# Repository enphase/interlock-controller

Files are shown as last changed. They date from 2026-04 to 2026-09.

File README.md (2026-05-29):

# interlock-controller

## ⚠️ DISCLAIMER ⚠️

This design is provided for reference and development purposes only.
It is not certified, not validated, and not intended for use as a safety‑critical control system without independent verification, validation, and certification by the user.
Enphase makes no representations regarding fitness for safety‑related use, including protection of persons, property, or equipment.

Any use of this design in systems that may cause harm, injury, or damage is solely at the user’s risk.
Users are responsible for compliance with applicable safety standards, regulations, and certifications.

## Introduction

This is a design for a controller box for an interlock system, including interface definitions, mechanical designs and wiring diagrams.
Broadly, it takes in inputs (like E-stops, magnetic sensors, and a start button) and provides outputs (closing an external dry contact loop) and a status light.
The design makes heavy use of 3d printing to be modular and allow iteration and design changes.

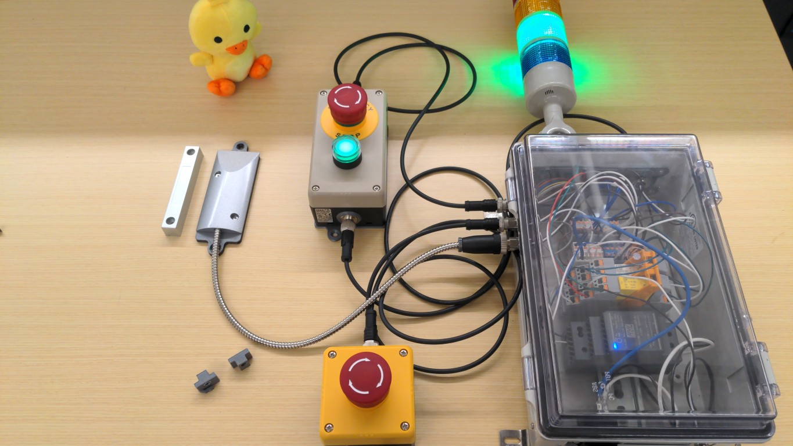
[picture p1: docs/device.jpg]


## General Design Rules

- Uses metric fasteners (M3 and M4 screws and nuts, both countersunk and pan head).
- 3d printed parts use friction-fit hex nuts.
- Uses 4-pin M12 connectors for sensors and outputs.
- Attaches to T-slot ("8020") framing, using M4 screws.

## Design Documents

[design.md](design.md) has detailed interface specifications.

## Mechanical Designs

Parts are designed in either Cadquery (a Python library for defining programmatic 3d designs) or FreeCAD.

Generated STLs are not committed to the repository, these can be generated by either running the CadQuery (`.py`) scripts or exporting from FreeCAD.
STLs MAY be included in the releases.

We have printed our parts on a Prusa XL using a high-flow 0.4mm nozzle and set for 0.2mm STRUCTURAL or 0.2mm BREAKAWAY INTERFACE, with PETG material (and PLA breakaway where needed).
These are expected to work on most FDM printers.
Unless otherwise noted, most parts can be printed in an orientation that does not require support. 

### T-slot Nuts

[tslot_nut.py](tslot_nut.py) generates a parametric T-slot nut with a hex nut pocket and spring arm to hold its position.
Print in PETG for flexibility of the spring arm.
You may need to tune parameters.

These are parameterized for 4545 metric T-slot framing.

### Controller Box and Connector Panels

The main controller box is a COTS box (NBB-10261) with machined cutouts (rounded rectangle + 4 M3 mounting holes) for 3d printed panels to fit connectors.
These can be purchased as a modified enclosure from Bud (with additional lead-time and $450 minimum order), through one of their distributors.
Alternatively, these can be machined (**not easily! needs special fixturing!**) on a manual mill and a 3/4" or 20mm end mill.

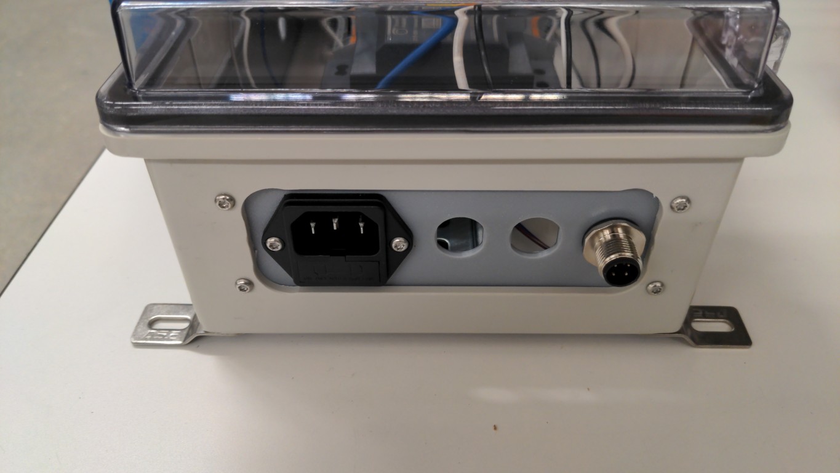
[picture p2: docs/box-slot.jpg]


Previously, this was two 116x40mm R10mm slots (top and bottom) and a 216x40mm R10mm slot (side), with M3 holes on a 124x32mm and 224x32mm pattern, respectively.
Newer version will have 116x40mm R10mm slots on three sides, with M3 holes on a 124x32mm pattern.

[connector_plate.py](connector_plate.py) generates the connector plates to fit into the cutouts.
These hold a M3 nut and have connector cutouts for eg, M12 connectors.

Electronics, like relays, are mounted to a DIN rail on the controller box.
The DIN rail is attached to factory-provided M4 threaded inserts / bosses in the box.
[din35_mount_stabilizer.py](din35_mount_stabilizer.py) generates a prismatic standoff that sits below the DIN rail to give it stability.
It can also be used to join two DIN rails back-to-back.
We use three of them: one next to each boss, and one to join two DIN rails; this seems to provide enough stability for DIN-mount spring-actuated terminal blocks.

If you are machining the box yourself, see [manufacturing-notes.md](manufacturing-notes.md).

See [design.md](design.md) for the electronics inside the box.

### Control Boxes

Human interface boxes (like for e-stop and pushbutton switches) use IDEC boxes like FB1W-111Y and FB2W-211Z, which are mounted to the T-slot framing using adapter plates.

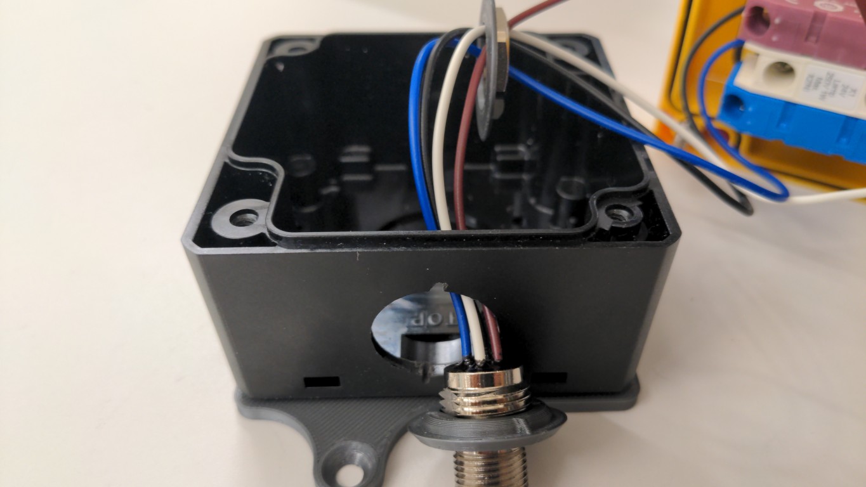
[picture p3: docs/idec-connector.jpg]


These have a 21.3mm punchout, which is too large for M12 connectors.
[idec_fb_m12_adapter.FCStd](idec_fb_m12_adapter.FCStd) and [idec_fb_m12_washer.FCStd](idec_fb_m12_washer.FCStd) "sandwich" the M12 connector to adapt it to the larger punchout.
idec_fb_m12_adapter.FCStd must be printed with supports, preferably two-material breakaway supports.
Because these add thickness, the O-ring on the M12 connectors must be removed.
Additionally, these have an anti-rotation feature, so a 1mm wide x 2mm long (radially outward) slot needs to be dremeled into the top of the punchout.
The anti-rotation feature is triangular, the slot does not have to be completely through.

[tslot_mounting_plate.py](tslot_mounting_plate.py) generates adapter plates that adapt the back of these boxes to attach to the T-slot framing.
These attach to the back of the IDEC box using M4 countersunk screws.
You will need to tap the factory holes on the box with a M4 tap.

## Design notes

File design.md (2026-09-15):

## External Connections

### Sensors

- 2x emergency stop switch w/ red light
  - This light indicates when the interlock is closed (output live)
- 1x magnetic door switch
- 1x start button w/ green light
  - This light indicates when the interlock is ready (output not live, but can be started by pushing this button)
  - Both e-stop lights AND start lights are on when the interlock is closed (output live).

### Output

- 1x dry contact output, connected to the test equipment interlock port
- 1x tower light
  - red = interlock closed (output live)
  - green = interlock open
  - no lights on or both lights on = invalid state
- Lights on e-stop and pushbuttons

## Interface definition

Inputs and outputs use M12 connectors, 4 or 5 pin versions, A-code.
For maximum compatibility, where not otherwise constrained, we use M12 4-position pins and M12 5-position sockets.

Outputs (eg, dry contact) are M12 sockets, while inputs (eg, sensors) are M12 pins.

The general pinning is, as consistent with IEC 60947‑5‑2:
- 1 (brown): +24v
- 3 (blue): 0v
- 2 (white): signal 1 (interlock loop source)
- 4 (black): signal 2 (interlock loop return)
- 5: disconnected where not used

Specific pinnings:
- For the e-stop: pin 1 (+24) is the interlock-closed +24v signal, which powers the e-stop light. 0v is always present.
- For the start button: pin 1 (+24) is the interlock-ready +24v signal, which powers the start button light. 0v is always present.
- For the tower light, if using M12 connectors: signal 1 is red, signal 2 is green (polarity dependent on the tower light configuration). 24v and 0v are always present.

Part selections:
- M12 5-position socket 0.2m pigtail: T4171310005-001
- M12 4-position pin 0.2m pigtail: T4171210004-001
- M12 5-position pin 0.2m pigtail (if needed): T4171210005-001
- Cables: M12A05ML-12AFL-Sx00x

## Electrical architecture

Internal wiring color conventions for terminal blocks and non-connector-pigtail wires ([source](https://industrialmonitordirect.com/blogs/knowledgebase/24v-dc-control-wiring-wire-color-codes-ul-en-standards)):
- Blue: +24v
- White: 0v
- Purple: interlock-ready +24v
- Orange: interlock-closed +24v
- Grey: general signal

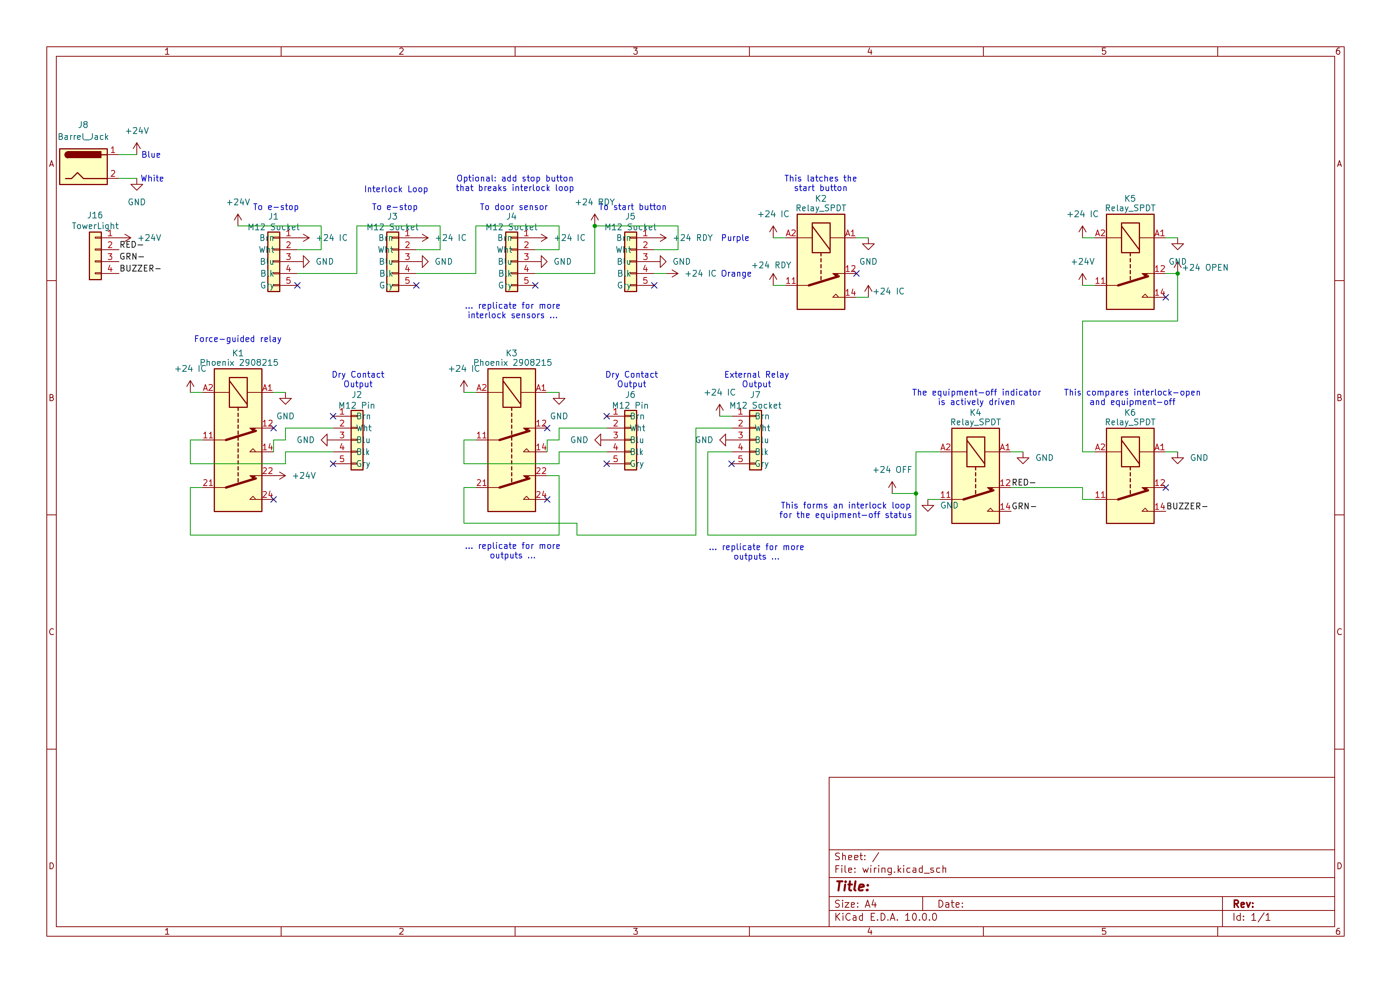
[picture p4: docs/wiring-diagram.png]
Wiring Diagram


- 24v architecture, as is common for industrial automation.
- Interlock loop starts at 24v and goes through (through and back) all the sensor ports, ending in the interlock-ready +24v rail.
  - This feeds the start button LEDs.
- The interlock loop then goes through the parallel combination of the start button and a relay that is powered by the interlock-closed +24v signal, ending in the interlock-closed +24v signal.
  - This provides latching-trip, push-to-reset functionality.
  - This feeds the e-stop switch LEDs.
- The interlock-closed +24v powers the force-guided relays (FGRs) that provide independent dry contact outputs per output.
- The force-guided channel from the output relay controls the tower lights.
  - The tower light RED is connected to ALL of the FGR NOs.
  - The tower light GREEN is connected to ALL of the FGR NCs.
  - The FGR common is connected to 0v (for a common-anode tower light).
  - Structurally, the tower light indicates output state, it should be consistent with the e-stop light in the absence of faults.
  - A single relay failure can lead to an inconsistent state with both red and green LEDs active, which is an invalid state requiring repairs.

Part selections:
- New power entry architecture
  - Any 24v barrel jack brick, preferably with UL or TUV, eg https://www.amazon.com/dp/B08T636YVR
  - Panel-mount barrel jack: https://www.amazon.com/dp/B091PS6XQ4
- Old power entry architecture
  - C13 with fuse: 719W-00/02
    - Note, nonstandard thin quick-disconnect connectors! 
  - Fuse: 5x20mm fuse:
    - 250mA slow: 0034.3111
    - 500mA fast: 0034.1513
  - 120->24 converter: HDR-30-24
- Standard relay: Phoenix 2903342
- Force-guided relay: Phoenix 2908215
- Terminal blocks: PTFIX series
  - 6-position blue: 3002761 PTFIX 6X1,5 BU
  - 6-position white: 3002778 PTFIX 6X1,5 WH
    - 12-position white: 3002779 PTFIX 12X1,5 WH
  - 6-position purple: 3002784 PTFIX 6X1,5 VT
  - 6-position orange: 3002792 PTFIX 6X1,5 OG
  - 6-position grey: 3002757 PTFIX 6X1,5 GY
    - 2-position grey (eg, to join two pigtail wires): 1045923 PTFIX 2X1,5 GY
  - DIN rail adapter: 1049497 PTFIX 1,5-NS35 

See [the reference box description](reference-box.md) for an example layout of the control box.

## External devices

- Box, 1-position (e-stop only): FB1W-111Y
  - 3d printed adapter to adapt to T-slot framing
- Box, 2-position (e-stop and start button): FB2W-211Z
- E-stop switch: PBES22L114R
  - Emergency stop label ring: HWAV-27-Y
- Start button: A22NL-BGM-TGA-G100-GC
- Door magnetic sensor: https://www.amazon.com/dp/B0BCYHBKVF
  - 3d printed adapter to adapt to T-slot framing 
- M12 adapter: https://www.amazon.com/dp/B0C2N777YG
  - 3d printed threaded endcap to retain the flange on the sensor cable 
- Tower light: https://www.amazon.com/dp/B09X14DK9M (common anode +12/+24v; yellow, blue, and buzzer channels unused and reserved for future expansion)

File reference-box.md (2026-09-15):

## General notes
- Jumper wires 16cm long
- Long jumper wires 24cm long
  - Only used for the barrel jack to the distribution blocks
- Coil and terminate unused wires (M12 5th pins)
- The Phoenix relays we use have polarized coil pins. A1 is +V, A2 is GND. **This differs from the wiring diagram.**

## Top row: rails

Top row:
- Grey terminal block (1-wide) x as many as needed: these bridge the interlock prev (M12 black) to interlock next (M12 white)

Bottom row:
- White terminal block (3-wide): GND
  - All button GNDs (M12 blue) wired here 
- Blue terminal block (3-wide): +24
- Purple terminal block (3-wide): +24 RDY
  - The start button LED line (M12 brown) is connected here
- Orange terminal block (3-wide): +24 IC
  - The e-stop LED lines (M12 brown) are connected here

## Center rows: relays

- Relay K2: start latch
- Relay K4: tower light control
- Relay K5: open inverter
- Relay K6: interlock compare
- output relays
  - These should be mirror contact relays since the tower light uses the readback state

Relay GNDs are daisy chained for wiring simplicity

## Bottom row: barrel jack breakout

- Grey terminal block (1-wide) x 2: bridge the short barrel jack lead to a longer wire to the main distribution block on the top row

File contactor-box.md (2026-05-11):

## External Contactor Box

To control devices without an interlock loop port, this box includes a mains-rated (240VAC) contactor powered from +24v.

This has an M12 pin connector pinned as:
- 1 (brown): +24v (switched) contactor control
- 3 (blue): 0v
- 2 (white): equipment-off interlock loop (readback) source (in)
- 4 (black): equipment-off interlock loop (readback) return (out)

For high current, this box has input and output NEMA L14-20 pigtails, plug on the input side and receptacle on the output side, connected via cable glands.
Suggested default: ~250mm pigtails.

For lower current (~10A), the box can have C13/C14 pigtails or panel-mountable connectors.

Parts selection:
- Contactor: 22.64.0.024.4717 (3NO + 1NC with mirror contact) or 3RT2026-1BB40 (3NO + NO and NC auxiliary contacts with mirror contact)
  - NO contacts used to switch line(s)
  - NC contact used for feedback
- Box: NBB-10260
  - Drill hit for AC in/out cable glands, as needed
  - Drill hit for 3d printed connector plate, ~20mm diameter round, with M3 mounting holes in 32x32mm pattern
    - 3d printed plate allows for anti-rotation feature and future interface changes
- DIN rail
- Terminal blocks to join grounds: PTFIX 2X4 GN, 1028364
- Terminal blocks to join neutrals (if present): PTFIX 2X4 WH, 1028366

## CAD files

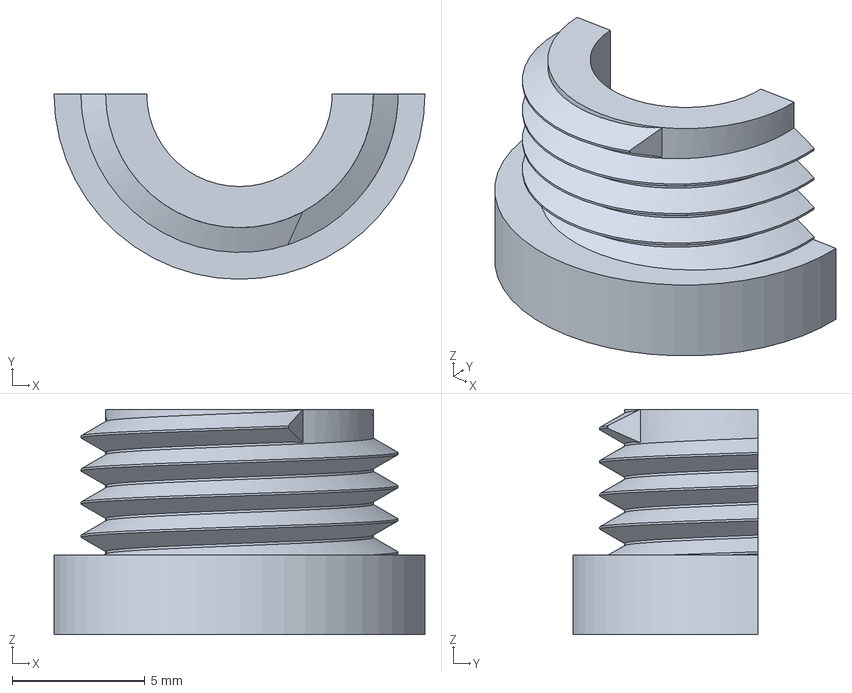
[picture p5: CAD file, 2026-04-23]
M12_cap.FCStd
14.0 x 7.00 x 8.50 mm

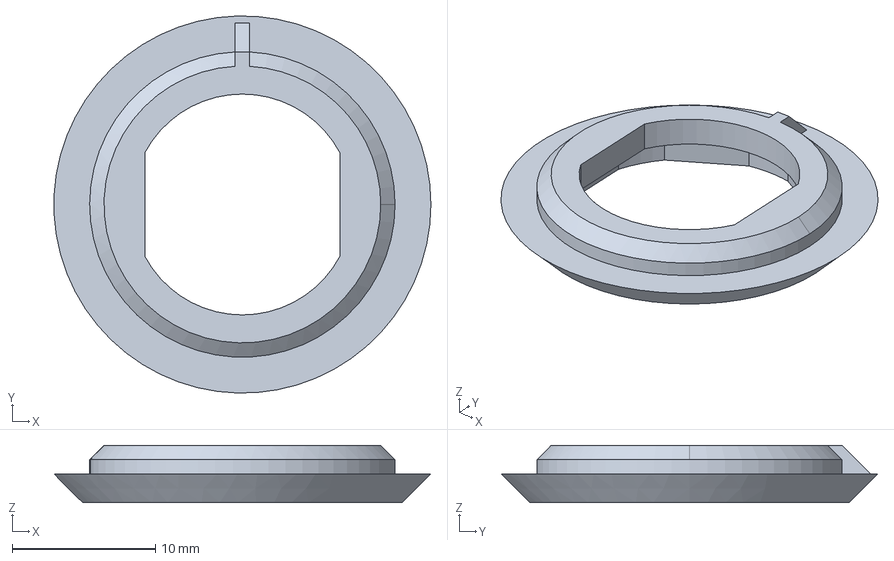
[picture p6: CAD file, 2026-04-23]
idec_fb_m12_adapter.FCStd
26.3 x 26.3 x 4.00 mm

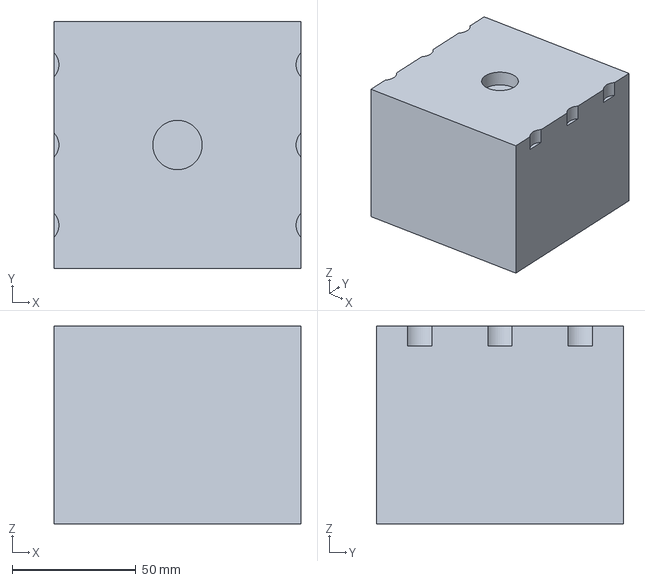
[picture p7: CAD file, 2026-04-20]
fixturing/nbb-10261-internal-clamp-fixture.FCStd
100.0 x 100.0 x 80.0 mm

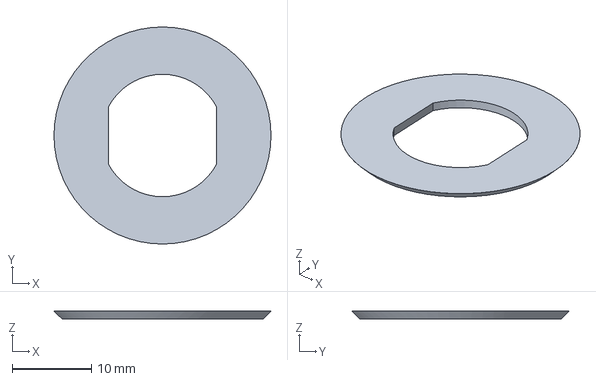
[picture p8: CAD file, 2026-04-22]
idec_fb_m12_washer.FCStd
27.3 x 27.3 x 1.00 mm

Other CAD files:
fixturing/relay-box-cutout-drawing.FCStd
fixturing/box-slot-drawing.FCStd

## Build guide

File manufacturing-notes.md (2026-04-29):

## Box Milling
- Use the internal-clamp-fixture to have the vise clamp against the box bottom face (instead of the edges and nubs)
- Apply a lot of pressure, possibly crushing the clamp fixture box as needed, to try to get contact against the side wall
- This will chatter, likely due to the face being milled being unconstrained and long/flat and vibrating
  - Clamping a block of wood to the face, even if not otherwise attached to the fixture, seems to help, possibly just from mass to dampen vibrations
  - Go slow on the spindle, 500rpm on a 3/4" end mill seemed to chatter less

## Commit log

2026-04-16 Design doc + not-yet-totally-cleaned-up plate design
2026-04-16 wip cleaning up to main plate gen
2026-04-17 ac power entry
2026-04-17 all thje plates
2026-04-17 tuning and clamp fixture
    [nbb-10261-internal-clamp-fixture.FCStd]
2026-04-20 tower light plate + improved m12 chamfer
2026-04-20 machining drawings
    [box-slot-drawing.FCStd, nbb-10261-internal-clamp-fixture.FCStd]
2026-04-22 wip adapters
    [box-slot-drawing.FCStd, idec_fb_m12_adapter.FCStd, idec_fb_m12_washer.FCStd]
2026-04-23 wip and notes
    [M12_cap.FCStd, idec_fb_m12_adapter.FCStd]
2026-04-23 t slot nut generator
2026-04-27 idec box mount adapter
    [idec_box_mounting_adapter.FCStd]
2026-04-27 wip tslot nut using shapely
2026-04-27 the box adapter is pretty trash
    [idec_box_mounting_adapter.FCStd]
2026-04-27 generic plate generator
2026-04-27 final adapter plates
2026-04-28 fix adapter plate for magnetic sensor
2026-04-29 Add wiring diagram
2026-04-29 add pictures, add wiring diagram source
    [wiring.kicad_sch]
2026-05-02 Update wiring diagram with equipment-off based indicator and mismatch detect
    [wiring.kicad_sch]
2026-05-02 add relay box concept
    [wiring.kicad_sch]
2026-05-06 corrected wiring diagram
    [wiring.kicad_sch]
2026-05-06 fixture device tuning
2026-05-06 update schematic w/ barrel jack sym
    [wiring.kicad_sch]
2026-05-07 wip and box cutout drawings
    [relay-box-cutout-drawing.FCStd]
2026-05-21 Tighten hex nut tolerancing
2026-05-29 Add mounting plate for wire organizers
2026-09-02 Add dropin t-slot nut
2026-09-15 v2 design (#1)
    Changes main box plate connectors, mostly connector cutout positions. Changes the side plate to be 116mm long (instead of 216 previously) to reduce flimsiness.
    Adds a reference box circuitry layout.
